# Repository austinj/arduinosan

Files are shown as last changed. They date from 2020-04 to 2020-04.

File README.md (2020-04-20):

# arduinosan
## Artisan-compatible arduino sketches and tutorial for sensing bean temp and ambient temp

### NOTE: Gullygossner [pointed out](https://www.reddit.com/r/roasting/comments/g4aodl/arduino_to_artisan_code_and_walkthrough/fnwm0se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) that I messed up my terminology in a fairly significant way. I said I was measuring ET, but I'm actually measuring ambient temperature This'll require some changes to the Artisan set-up. Right now, ambient temperature is being registered as ET in Artisan. My mistake. Update coming soon! [4/20/20]

When you're roasting coffee, it's nice to be able to measure the temperature within the bean mass that you're roasting. Knowing the ambient temperature is nice too, since it'll impact the corresponding energy and time that needs to be input into the roast. However, if you're using a roaster that lacks a thermocouple or thermistor, you need to roll your own solution. You can buy one off the shelf (except it won't have ambient temp, so come on), but where's the fun in that? Let's make our own!

Since you're collecting these temperature data digitally, you probably also want to record and monitor them digitally as well. Artisan is open-source roasting software that facilitates the generation of roasting curves, which are the core tool for understanding and adjusting a roast as it happens. Getting data to Artisan can be pretty tricky.

There are a handful of solutions out there for solving this fun little niche problem, but most of them aren't very well documented. So, here we go!

### Electronics configuration

#### Stuff you'll need
##### Core components
- Metro 328 [(Adafruit)](https://www.adafruit.com/product/2488)
- PT1000 RTD Temperature Sensor Amplifier - MAX31865 [(Adafruit)](https://www.adafruit.com/product/3648)
- PT1000 Platinum RTD sensor [(Adafruit)](https://www.adafruit.com/product/3984)
- DHT11 basic temperature-humidity sensor + extras [(Adafruit)](https://www.adafruit.com/product/386)
  - You need a 4.7K or 10K resistor to pull it up, which is the "extra" that's included
##### Other stuff you'll probably need if you don't have it lying around
- Breadboard [(Adafruit)](https://www.adafruit.com/product/64)
- Jumper wires or other wire for breadboarding [(Adafruit)](https://www.adafruit.com/product/153)
- Micro USB to (your USB flavor here, mine's USB C) for Metro 328 [(Adafruit)](https://www.adafruit.com/product/3878)
  - Make sure the cable is *not* data-only if you want to run power through it instead of the DC jack
##### Optional but nice
- Mounting plate for Metro 328 and breadboard [(Adafruit)](https://www.adafruit.com/product/275)
##### If you've never done an electronics project before, you'll also have to get
- Soldering iron
- Solder
- Diagonal cutters
- X-Acto knife (because you have to cut a wire on the MAX31865)
- But really, just buy [this electronics starter kit](https://www.adafruit.com/product/136), which includes a half-size breadboard too, so hey, cross that off your list

#### Directions

##### A. Get the MAX31865 ready

A1. Configure the board for a 3-wire set-up

If you've never worked with a PCB before, this is going to be an adventure. Some PCBs you buy require actual physical changes to the board to make them work for your specific configuration. These are referred to as "jumpers". The MAX31865 has jumpers to configure the board for 2-, 3-, or 4-wire RTD sensors. We're using a 3-wire, so we've got to do two things.

First, we cut a wire between two pads. "Cutting a wire" on a board means you're straight up using a razor to slice through a tiny line of copper that's making a connection. You're cutting the wire that connects (a) the pad that is directly above the "24" text and (b) the pad to its right. So, take your x-acto, and cut that thing. Realize that you need to get down in there, so trust yourself to apply some pressure and slice that copper out.

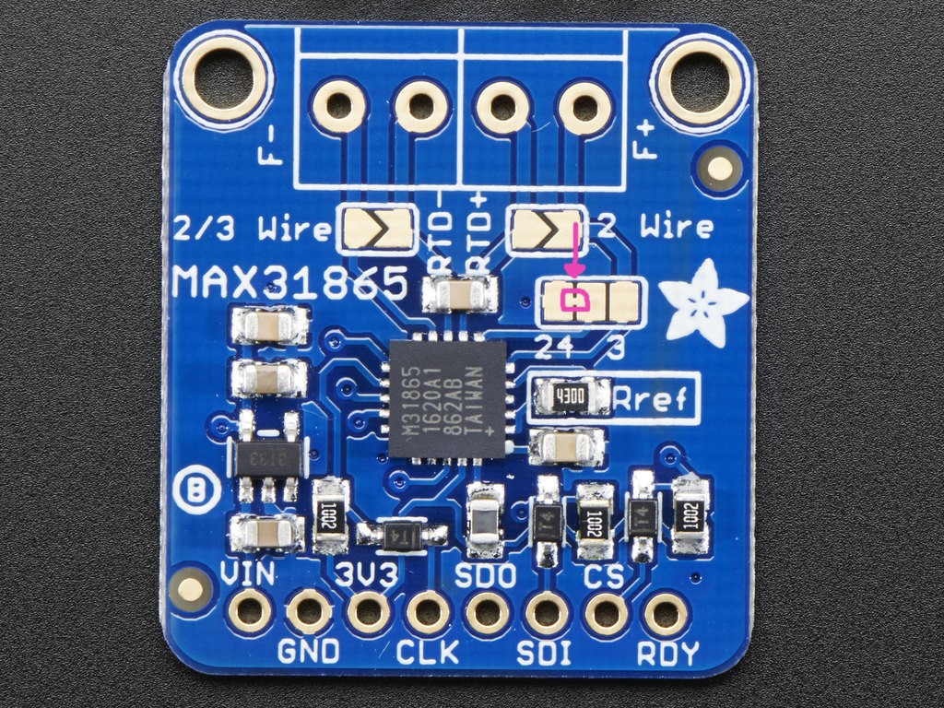
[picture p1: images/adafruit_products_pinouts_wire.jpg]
cutting Cutting the wire


Second, we solder two pads together in two separate places. You're soldering the (a) 2/3 wire pads and (b) the two right-most pads above the "24 3" text.

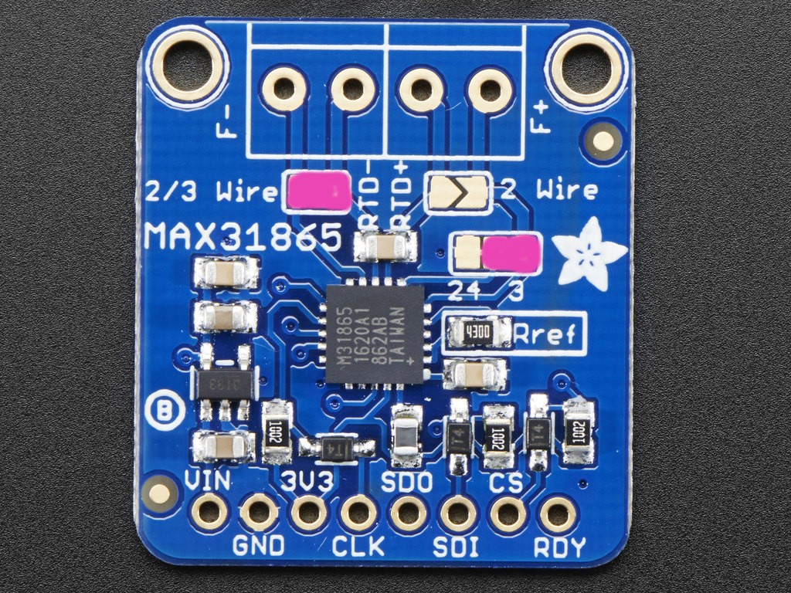
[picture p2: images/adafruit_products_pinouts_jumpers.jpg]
jumping Jumping the pads


A2. Solder the headers and terminal blocks on

Use [this guide](https://learn.adafruit.com/adafruit-max31865-rtd-pt100-amplifier/assembly) from Adafruit; it walks you through this whole step with lots of lovely pictures.

##### B. Wire up everything
B1. Connect the RTD sensor to the MAX31865

Use [this guide](https://learn.adafruit.com/adafruit-max31865-rtd-pt100-amplifier/rtd-wiring-config#3-wire-sensors-4-10) from Adafruit to see how to get the wires from your 3-wire RTD sensor into the contacts. The terminals at the end of the wires are forked, but this makes them a really bad fit for the terminal blocks, so either snap one end of the terminal off (which is what I did) or I guess you could try and smash them together? I don't know, I just wiggled one end of the terminal on each wire back and forth with some needle-nose pliers until it snapped off.

B2. Wire up everything else, including your DHT11 environmental sensor. Just follow this fun diagram!

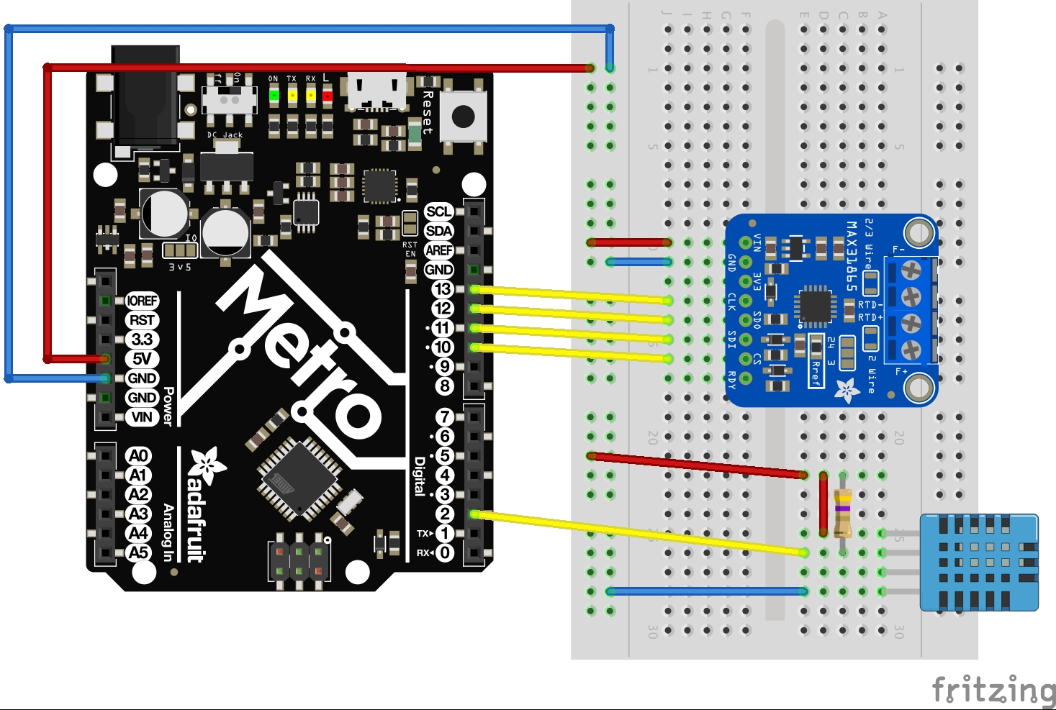
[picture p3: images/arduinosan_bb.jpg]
fritzing Fritzing diagram


##### C. Upload the arduino sketch to the Metro 328

Download "max31865_dht_artisan.ino" from this repository. Open it up in Arduino and push it to your Metro 328. It's not sending anything to your serial monitor, so don't look for anything in there. It's time for some Artisan config screens.

##### D. Configure Artisan

Oh, this is fun. You'll be using MODBUS protocol.

1. Open Artisan
2. Go to Config \ Device...
3. Select Meter:MODBUS

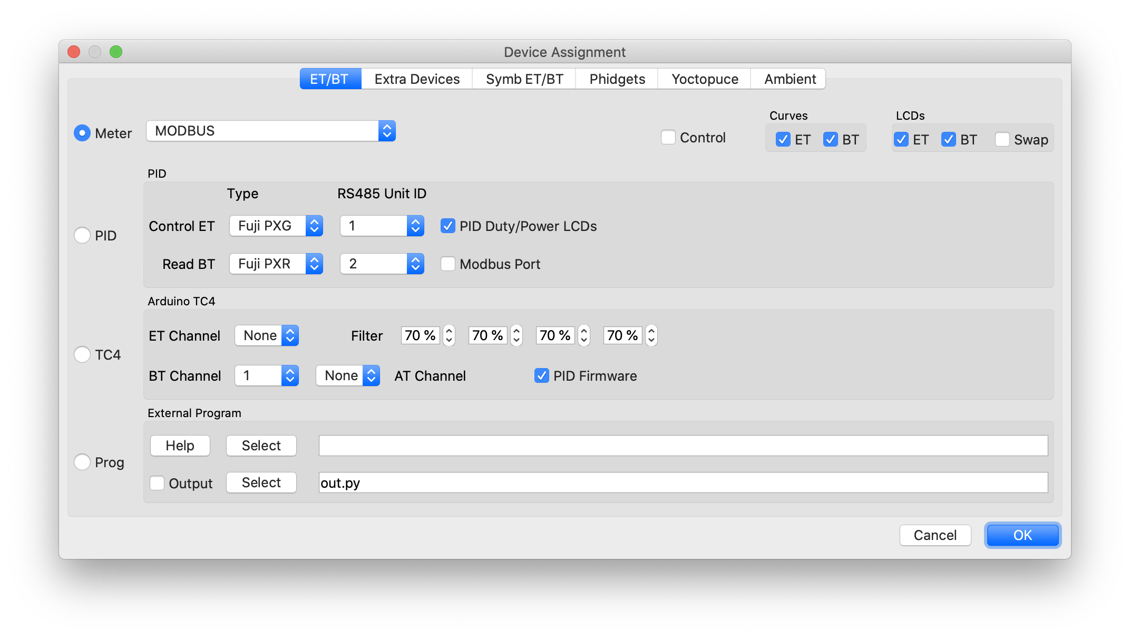
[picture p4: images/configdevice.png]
configdevice Config \ Device


4. After you press OK, you'll get sent to the Ports Configuration window.

5. Before we move on, we need to identify the path for your Metro 328's serial port.

6. Make sure your Metro 328 is on and talking to your computer.

7. If you're running OS X like me, open a terminal window and enter `ls /dev/tty.*`. From those entries listed, you gotta figure out which one is your port name. I used [this thread from StackOverflow](https://stackoverflow.com/questions/12254378/how-to-find-the-serial-port-number-on-mac-os-x). Mine was "/dev/tty.SLAB_USBtoUART" (note that you need the whole path name, including "/dev/"!). If you're not running OS X, or if you think you're doing this part wrong, just Google around for "serial port [your operating system here]", maybe add "arduino" or "metro 328" in there. You should be able to figure it out.

8. Pop your serial port name into "Comm Port" and then set everything else to match below.

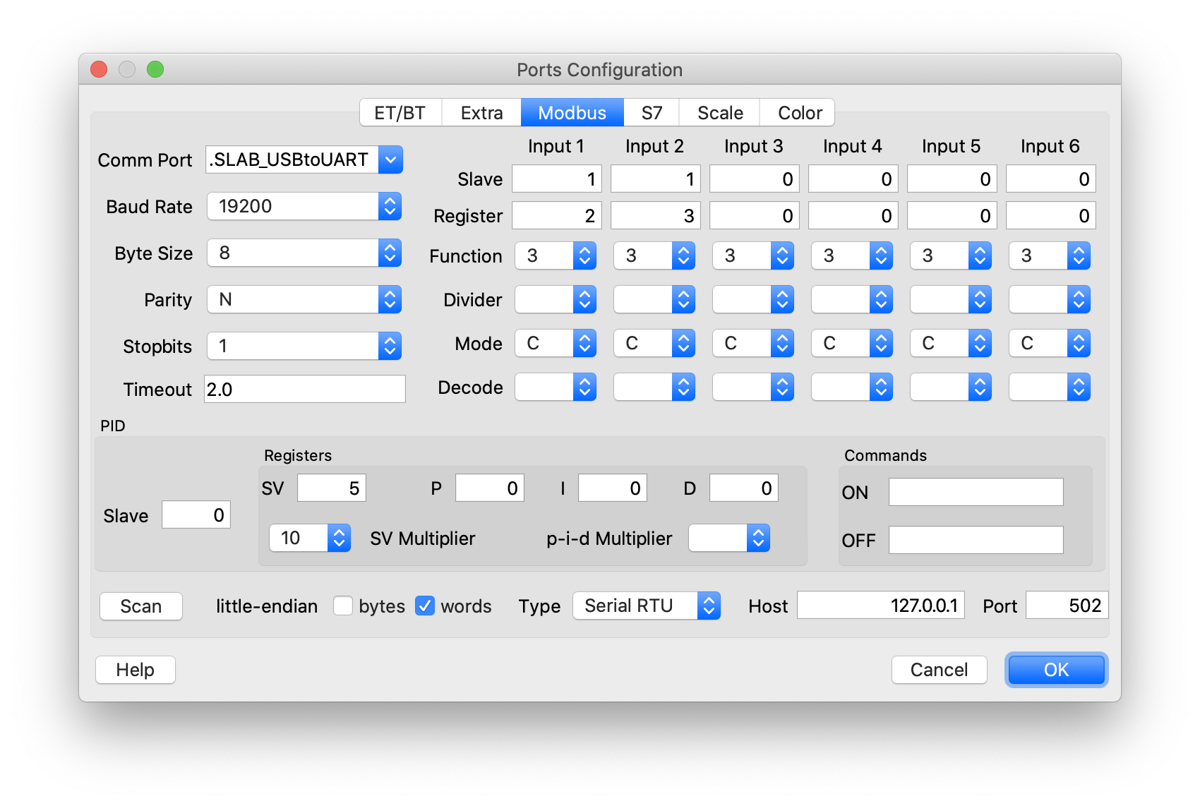
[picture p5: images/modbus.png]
modbus Modbus


9. Click OK, and start up a roast in Artisan! You should see values for ET (even though this is actually ambient temp, change coming soon) and BT. You did it.

##### E. Roast some coffee!

May I suggest a [lovely East African dry process](https://www.sweetmarias.com/ethiopia-organic-dry-process-sidama-keramo-6287-2.html)?

### Credits

- [Lukeinator42's Artisan-friendly modbus arduino sketch](https://github.com/lukeinator42/coffee-roaster)
- [Adafruit's MAX31865 documentation](https://learn.adafruit.com/adafruit-max31865-rtd-pt100-amplifier/overview)
- [Adafruit's DHT11 documentation](https://learn.adafruit.com/dht/using-a-dhtxx-sensor)
- [This thread on home-barista.com](https://www.home-barista.com/home-roasting/getting-artisan-to-talk-to-arduino-t58234.html)
- [Adafruit Discord, thanks @nis for being a great teacher](https://discordapp.com/invite/adafruit)

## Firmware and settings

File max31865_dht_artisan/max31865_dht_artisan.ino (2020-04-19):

/*************************************************** 
  ARDUINOSAN 1.0
  For sensing bean temp and environmental temp and sending it to Artisan

  Slapped together by Austin Johnson (austinj@gmail.com)

  Code mostly adapted from:

  1. Lukeinator42 - https://github.com/lukeinator42/coffee-roaster
  2. This Adafruit library - https://github.com/adafruit/DHT-sensor-library
  3. And this Adafruit library -->
  
  This is a library for the Adafruit PT100/P1000 RTD Sensor w/MAX31865

  Designed specifically to work with the Adafruit RTD Sensor
  ----> https://www.adafruit.com/products/3328

  This sensor uses SPI to communicate, 4 pins are required to  
  interface
  Adafruit invests time and resources providing this open source code, 
  please support Adafruit and open-source hardware by purchasing 
  products from Adafruit!

  Written by Limor Fried/Ladyada for Adafruit Industries.  
  BSD license, all text above must be included in any redistribution
 ****************************************************/


#include <Adafruit_MAX31865.h>
#include "DHT.h"
#include <ModbusRtu.h>



// data array for modbus network sharing
uint16_t au16data[16] = { 0, 0, 0, 0, 0, 0, 0, 0, 0, 0, 0, 0, 0, 0, 1, -1 };
/**
 *  Modbus object declaration
 *  u8id : node id = 0 for master, = 1..247 for slave
 *  u8serno : serial port (use 0 for Serial)
 *  u8txenpin : 0 for RS-232 and USB-FTDI 
 *               or any pin number > 1 for RS-485
 */
Modbus slave; // this is slave @1 and RS-232 or USB-FTDI



// Use software SPI: CS, DI, DO, CLK
Adafruit_MAX31865 thermo = Adafruit_MAX31865(10, 11, 12, 13);
// use hardware SPI, just pass in the CS pin
//Adafruit_MAX31865 thermo = Adafruit_MAX31865(10);

// The value of the Rref resistor. Use 430.0 for PT100 and 4300.0 for PT1000
#define RREF      430.0
// The 'nominal' 0-degrees-C resistance of the sensor
// 100.0 for PT100, 1000.0 for PT1000
#define RNOMINAL  100.0

int ssr = 5;  


#define DHTPIN 2     // Digital pin connected to the DHT sensor
// Feather HUZZAH ESP8266 note: use pins 3, 4, 5, 12, 13 or 14 --
// Pin 15 can work but DHT must be disconnected during program upload.

// Uncomment whatever type you're using!
#define DHTTYPE DHT11   // DHT 11
//#define DHTTYPE DHT22   // DHT 22  (AM2302), AM2321
//#define DHTTYPE DHT21   // DHT 21 (AM2301)

DHT dht(DHTPIN, DHTTYPE);



void setup() {
  thermo.begin(MAX31865_3WIRE);  // set to 2WIRE or 4WIRE as necessary
  dht.begin();
  pinMode(ssr, OUTPUT);
  slave = Modbus(1,0,0);
  slave.begin( 19200 ); // 19200 baud, 8-bits, even, 1-bit stop
  delay(5);
}

void loop() {
  
   au16data[2] = ((uint16_t) thermo.temperature(RNOMINAL, RREF));
   au16data[3] = ((uint16_t) dht.readTemperature());
   
   slave.poll( au16data, 16 );

   for(int i=1; i<=99; i++) {
    if(i<=au16data[4])
      digitalWrite(ssr, HIGH);
    else
      digitalWrite(ssr, LOW);
    
    delay(5);
   }
   
}

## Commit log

2020-04-19 Add fritzing diagram
    [arduinosan.fzz]
2020-04-19 Realize DHT11 code is broken
    [max31865_artisan.ino, max31865_dht_artisan.ino]
